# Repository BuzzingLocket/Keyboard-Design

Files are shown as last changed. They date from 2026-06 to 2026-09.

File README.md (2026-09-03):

# May 8th 2026 Initial Release 🚀
- 80% keyboard ansi
- Missing a ctrl key on the righthand side
- Uses a Raspberry Pi Pico as the MCU, I was too lazy to implement my own rp2040 MCU design
- Firmware will be updated at a later date
- Everything is designed to be hand soldered
- Printed using a lpkf protomat s103 with traces at 0.4mm, and vias at 0.6mm

# May 14th 2026 Hotfix 🛠️
- lpkf protomat s103 requires vias at 0.8mm diameter with a hole of 0.4mm
- Not the same as 0.6mm diameter with a hole of 0.3mm
- Decided to print with JLCPCB instead of school PCB printer due to costs

# June 2nd 2026 Firmware Release 🚀
- Added QMK firmware
- Full matrix finished
- RGB added
- Could be errors, requires more testing
- QMK uses HSV (hue, saturation, value) not RGB (Red, Green, Blue)

# June 14th 2026 Firmware Update ⚡
- Finalized the QMK firmware
- Edited the rotary encoder resolution from 2 --> 4
- Switched GP21 and GP20 due to preference
- Finished testing keyboard
- Uploaded as .c file

# June 20th 2026 Case Design Release 🚀
- Learned how to use Fusion360
- Created bottom case housing
- Pillars for M2 screws and for support
- 4mm base depth
- 5mm wide walls
- 6mm pillars for pcb to lie on-top
- Designed for M2x4mm (3.5mm width) heat inserts
- Designed for M2x5mm screws
- Uploaded as .STEP and .STL

# June 20th 2026 Firmware Quality of Life ✨
- Uploaded .uf2 file for firmware
- Renamed folders for recognition
- Removed USB C datasheet as it was not used

# August 7th 2026 Keyboard Case Update⚡
- Had to go do some tasks for work so I could not update this for a while
- Went on vacation so long break was taken
- Old keyboard design was not accurate Ie. sides were 5.231mm not 5mm
- Added 1mm tolerance to each edge
- Added holes into the walls
  - Allows for a top portion of the case
      - Higher case level
      - Covers the exposed microcontroller
   
# August 9th 2026 Keyboard Case Update⚡
- Uploaded top case files .stl and .step
- Started the top case design
- Added pillars to insert into sockets from the bottom case
- Added a cover for the Pi Pico

# August 15th 2026 Keyboard Case Update⚡
- Updated bot case files .stl and .step
- Holes were too small as they shrunk when cooled
  - Expanded hole radius by 0.25mm
- Cover for pi pico on 1top case is accurate

# August 25th 2026 Keyboard Print Files Update⚡
- Finished certification and testing of all cases
- Purchasing filament
- Printing at Toronto Metropolitan Universities DME

# September 3rd 2026 Keyboard Print Files Update⚡
- Updated Keyboard print files
- Added a fin onto the back of the Bot_Case to make it print more stable
- Fin helps print diagonally without excessive use of filament from auto generated supports

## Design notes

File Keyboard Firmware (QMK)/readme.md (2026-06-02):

# v1

v1

*A custom keyboard by BuzzingLocket*

* Keyboard Maintainer: [Evan](https://github.com/BuzzingLocket)
* Hardware Supported: Raspberry Pi Pico RP2040
* Hardware Availability: Custom build

Make example for this keyboard (after setting up your build environment):

    make v1:default

Flashing example for this keyboard:

    make v1:default:flash

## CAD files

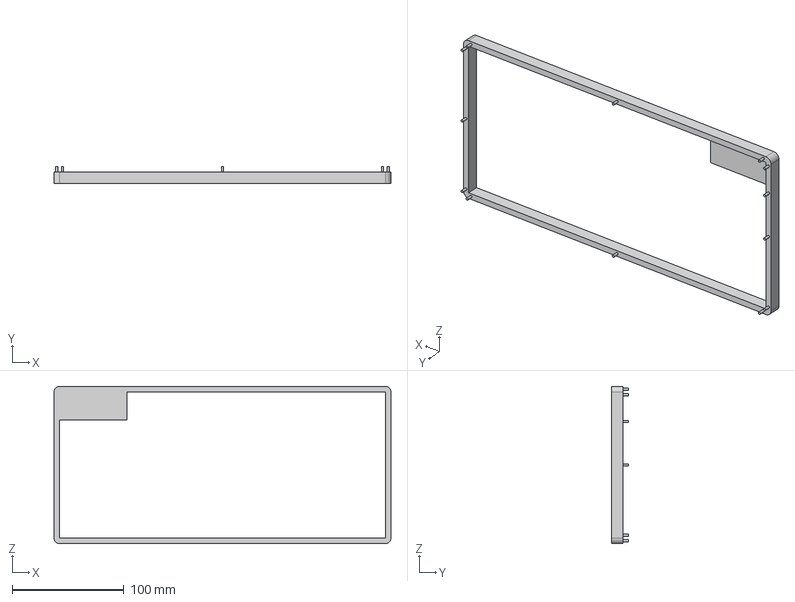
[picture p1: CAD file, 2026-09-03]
Keyboard Case/Top_Case.step
301.0 x 15.0 x 140.5 mm

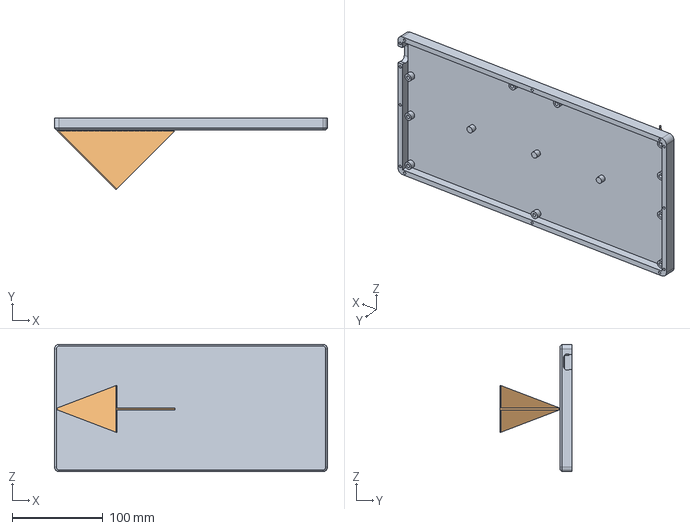
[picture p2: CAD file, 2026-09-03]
Keyboard Case/Bot_Case.step
301.0 x 79.0 x 140.5 mm

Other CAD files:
Keyboard Case/Bot_Case.3mf
Keyboard Case/Bot_Case.stl
Keyboard Case/Top_Case.3mf
Keyboard Case/Top_Case.stl

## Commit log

2026-06-20 Update README with case design and firmware info
    Added details about case design and firmware updates.
2026-06-20 Organizing project folders
    [Keyboard.kicad_pcb, Keyboard.kicad_sch, Leds.kicad_sch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]
2026-08-07 Updated case design
    [Bot_Case.step, Bot_Case.stl, Bottom_Case.step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]
2026-08-09 Added Top Case segments
    [Top_Case.step, Top_Case.stl]
2026-08-09 Add August 9th 2026 update to README
    Updated README with August 9th 2026 keyboard case details.
2026-08-15 Updated Bottom Case Files
    [Bot_Case.step, Bot_Case.stl]
2026-08-15 Update README with August 15th 2026 case changes
2026-08-25 Added printing files
    Still requires troubleshooting and need to purchase filament and acquire certifications for school printing
    [Bot_Case.3mf, Top_Case.3mf]
2026-08-25 Update README with August 2026 keyboard print files info
2026-09-03 Updated Keyboard Case Files
    [Bot_Case.3mf, Bot_Case.step, Bot_Case.stl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]
2026-09-03 Forgot to Upload Top_Case.STL
2026-09-03 Add September 3rd update for keyboard print files
